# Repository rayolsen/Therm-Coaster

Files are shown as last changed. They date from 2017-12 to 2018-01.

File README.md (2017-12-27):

# Temperature-Coaster

The idea is simple: create a drink coaster which indicates what temperature a drink placed on it is. whether hot or cold, by turning red or blue. The ideal use for this is to be able to tell if your coffee has gone cold.  

I plan on using ATTiny85 do the work, since it should run on 3v 
CR2023 is 3v and should have enough mA to power it and some SK6812 / 5050 RGB LEDS
And a thermresistor will sense the temp, obviously.

The end game is to dip the board in resin to waterproof and protect the board making into an actual coaster.
The bottom side of the board will have the battery holder and pads to program the Attiny85.  I plan on leaving a recess in the epoxy to allow battery access.  I may make a recess for the pads for debugging,  but i plan to work out the code and kinks before putting it in resin

---
This is intended to be an Entry for the [HackaDay Coin Cell Challenge](https://hackaday.io/contest/28283-coin-cell-challenge)

Keeping in with the rules of the challenge, i've added the board to [OSHPark](https://oshpark.com/shared_projects/DYg7IxAX) 



Future add-ons may include some IoT for notifying when the drink reaches a certain temp or something

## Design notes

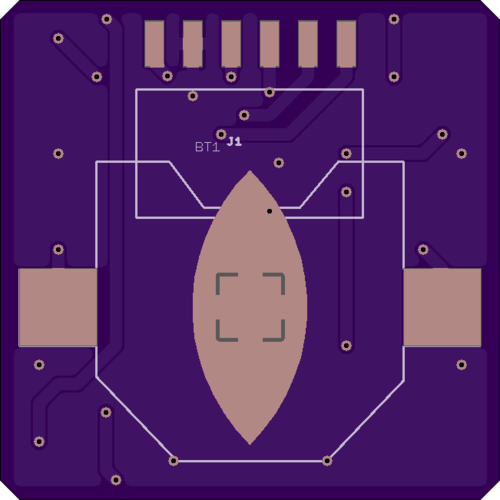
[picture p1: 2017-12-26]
Docs/board bottom.png

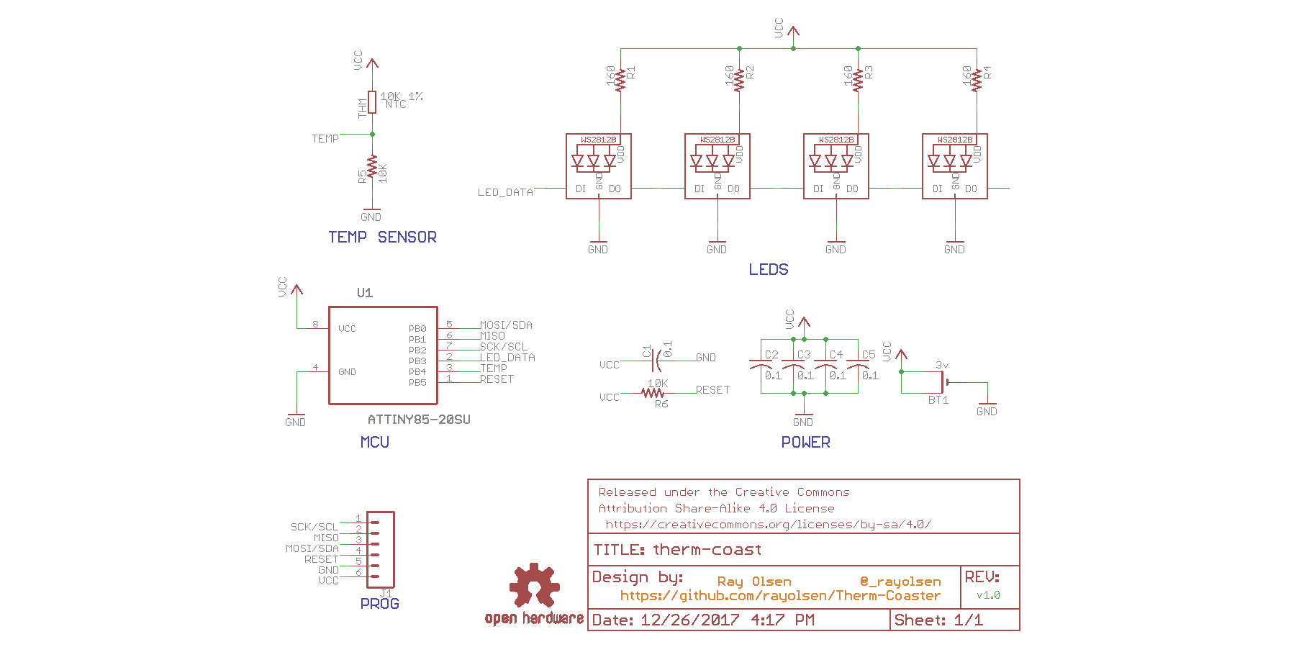
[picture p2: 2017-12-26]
Docs/Schem.png

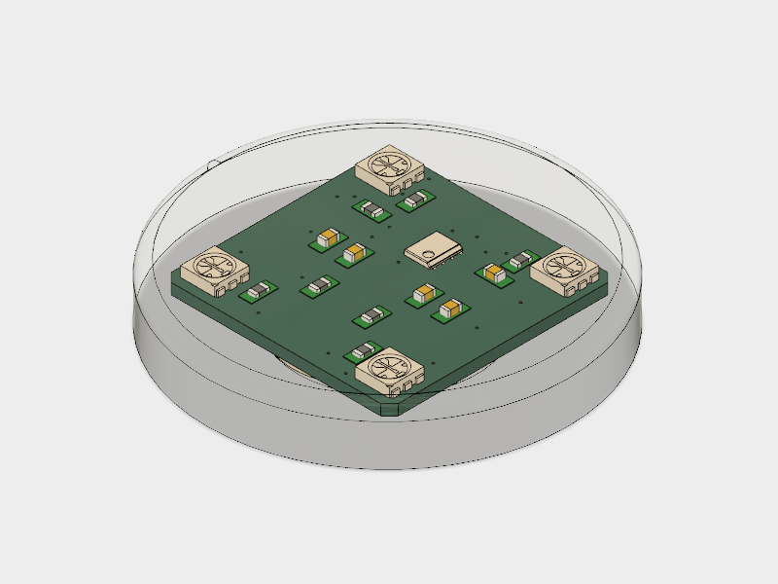
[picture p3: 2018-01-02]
Docs/therm-coast v4-ss.png

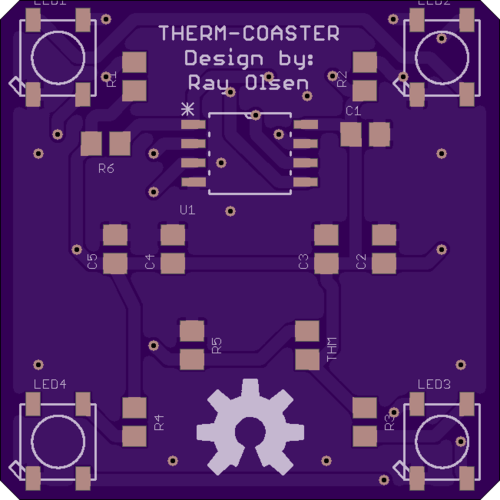
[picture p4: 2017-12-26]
Docs/board top.png

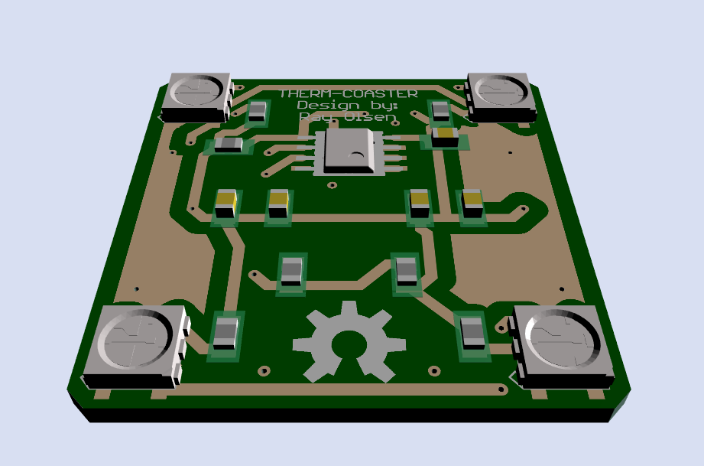
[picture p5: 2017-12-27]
Docs/screenshot.png

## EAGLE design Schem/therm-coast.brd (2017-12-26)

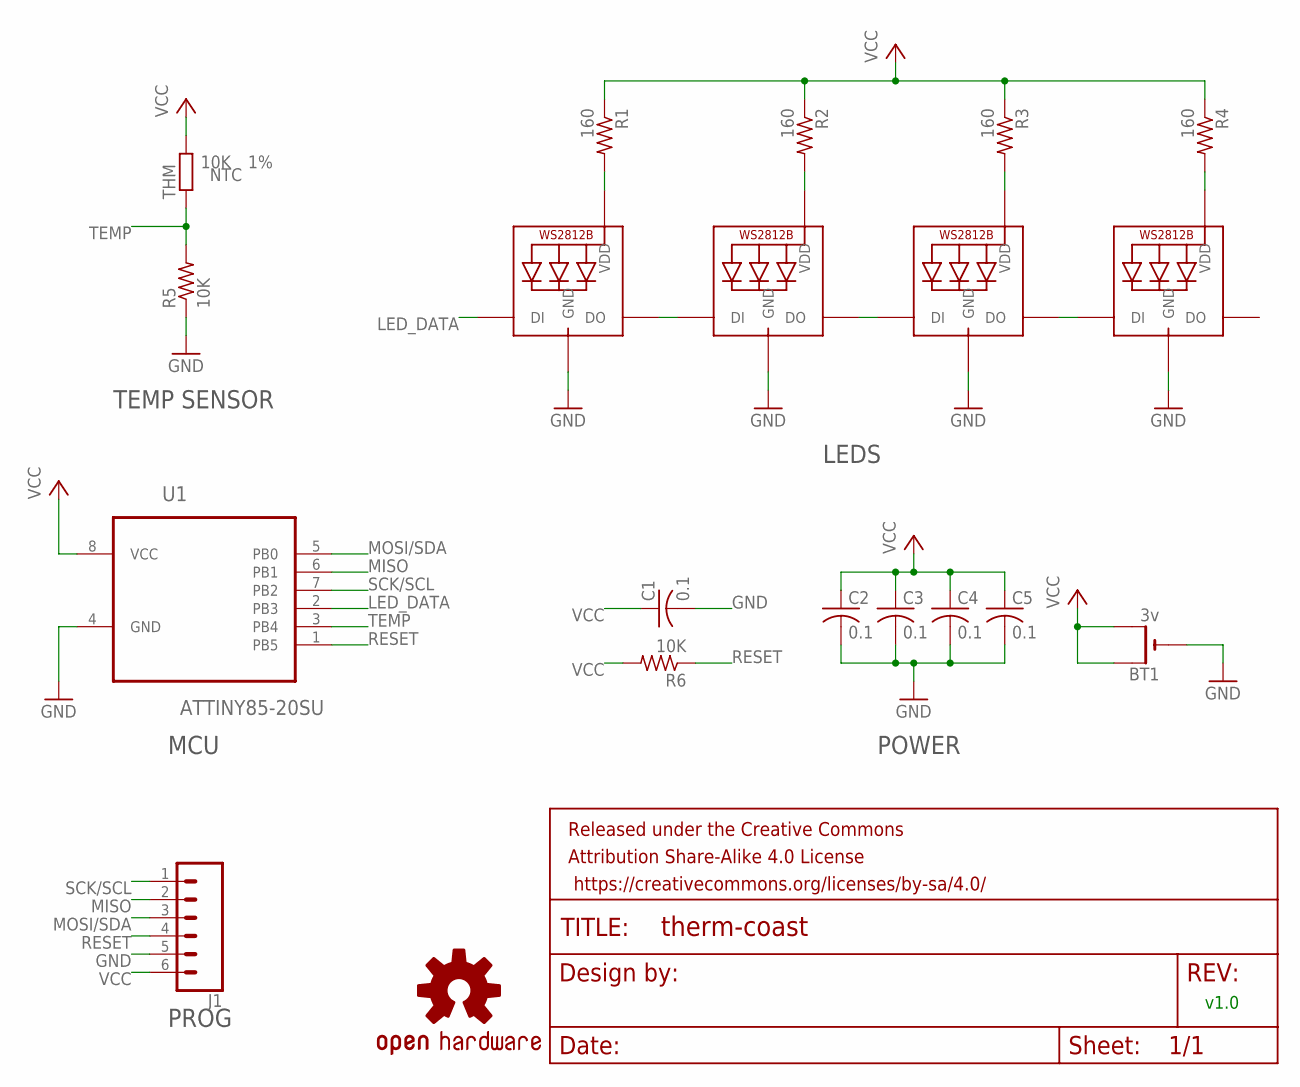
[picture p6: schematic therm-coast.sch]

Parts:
BT1: 3v; CR2032-SMD
C1, C2, C3, C4, C5: 0.1; C0805
FRAME1: FRAME-LETTER; CREATIVE_COMMONS
J1: CONN_06SMD-FEMALE-V2; 1X06-SMD-FEMALE
LED1, LED2, LED3, LED4: WS2812B5050; WS2812B
LOGO1: OSHW-LOGOL; OSHW-LOGO-L
R1, R2, R3, R4: 160; R0805
R5, R6: 10K; R0805
THM: 10K; R0805; TOLERANCE 1%
U1: ATTINY85-20SU; SOIC127P798X216-8N

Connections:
GND: BT1.-, C1.2, C2.2, C3.2, C4.2, C5.2, J1.5, LED1.3-GND (GND), LED2.3-GND (GND), LED3.3-GND (GND), LED4.3-GND (GND), R5.1, U1.4 (GND)
LED_DATA: LED1.4-DIN (DI), U1.2 (PB3)
MISO: J1.2, U1.6 (PB1)
MOSI/SDA: J1.3, U1.5 (PB0)
unnamed: LED1.1-VDD (VDD), R1.2
unnamed: LED2.1-VDD (VDD), R2.2
unnamed: LED3.1-VDD (VDD), R3.2
unnamed: LED4.1-VDD (VDD), R4.2
unnamed: LED1.2-DOUT (DO), LED2.4-DIN (DI)
unnamed: LED2.2-DOUT (DO), LED3.4-DIN (DI)
unnamed: LED3.2-DOUT (DO), LED4.4-DIN (DI)
RESET: J1.4, R6.1, U1.1 (PB5)
SCK/SCL: J1.1, U1.7 (PB2)
TEMP: R5.2, THM.1, U1.3 (PB4)
VCC: BT1.+$1 (+), BT1.+$2 (+1), C1.1, C2.1, C3.1, C4.1, C5.1, J1.6, R1.1, R2.1, R3.1, R4.1, R6.2, THM.2, U1.8 (VCC)

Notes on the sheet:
v1.0
TEMP SENSOR
MCU
PROG
LEDS
POWER

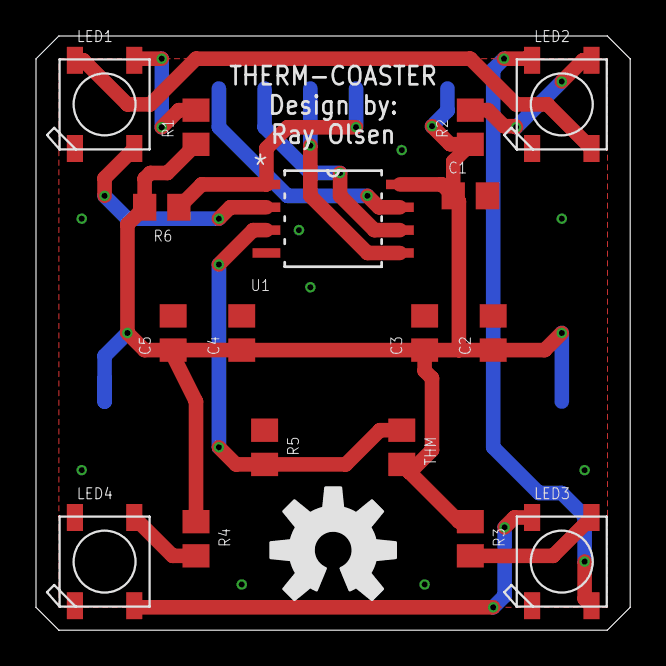
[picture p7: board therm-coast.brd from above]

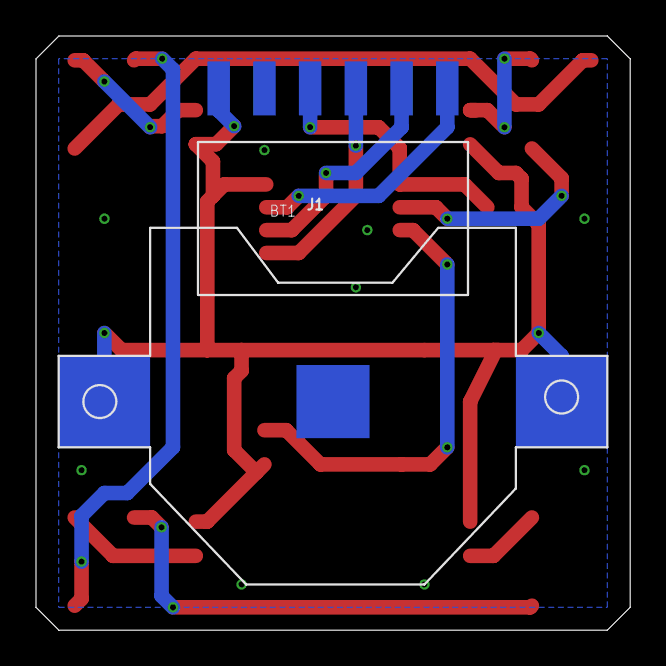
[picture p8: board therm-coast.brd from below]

Board: 2 copper layers, 33.0 x 33.0 mm, 21 parts (2 on the bottom side), 15 nets.

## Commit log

2017-12-13 schematic creation
    [therm-coast.sch]
2017-12-15 Schematic Design
    Added major components including LEDs, Thermsistor and some power regulation
    [therm-coast.sch]
2017-12-19 board design
    [therm-coast.brd]
2017-12-21 Board Placement and Routing updates
    [therm-coast.brd, therm-coast.sch]
2017-12-21 Rev 1.0
    Better Route and Placement, Silks
    [therm-coast.brd, therm-coast.sch]
2017-12-22 Fix #1
    Updates to fixz issue with vias exposed to ground plane
    [therm-coast.brd]
2017-12-22 Fix #1.1
    few fixes forgotten in last push
    [therm-coast.brd, therm-coast.sch]
2017-12-26 minor fixes
    [therm-coast.brd]
2017-12-26 Cleaned up for entry
    [therm-coast.brd, therm-coast.sch]

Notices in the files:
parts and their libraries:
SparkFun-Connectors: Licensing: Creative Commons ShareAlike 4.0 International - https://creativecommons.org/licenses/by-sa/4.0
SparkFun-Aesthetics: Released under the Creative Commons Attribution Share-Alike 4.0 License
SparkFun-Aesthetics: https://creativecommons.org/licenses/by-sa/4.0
